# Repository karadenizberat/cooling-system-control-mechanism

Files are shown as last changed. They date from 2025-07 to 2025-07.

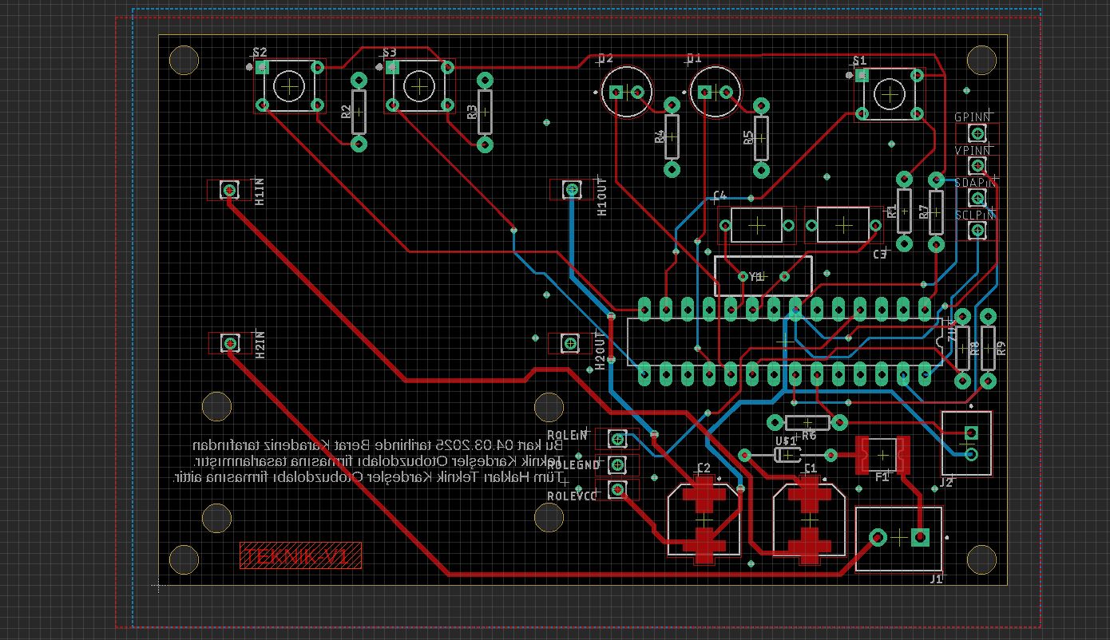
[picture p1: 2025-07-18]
img/coolingsystem-brd-img.JPG

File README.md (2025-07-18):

# 🚐 Vehicle Refrigerator Controller (ATmega-based)

This project is designed to control compact refrigerators used in
vehicles. It is based on an ATmega microcontroller and includes:

-   ❄️ Real-time temperature monitoring with an NTC sensor\
-   🔌 Relay control for compressor on/off\
-   📟 OLED display to show ambient and target temperatures\
-   💾 EEPROM storage for saving power state and target temperature\
-   🔘 Button interface to adjust temperature and toggle system on/off

The system continuously monitors ambient temperature and activates the
cooling system when needed. It is ideal for automotive refrigeration
applications requiring reliability and efficiency.

------------------------------------------------------------------------

## 🛠️ Hardware Components

-   ATmega microcontroller (e.g. ATmega328P)
-   NTC Thermistor
-   Relay module (12V/24V depending on compressor)
-   OLED Display (SSD1306 - 128x64)
-   EEPROM (onboard)
-   Push Buttons (Increase / Decrease / Power)
-   Green & Red LEDs for status indication

------------------------------------------------------------------------

## 📁 File Structure

Vehicle-Fridge-Controller/ │ ├── kod/ → Arduino source code (.ino file)
├── eagle/ → Circuit schematic (.sch) & PCB layout (.brd) ├── img/ →
Circuit photos, 3D renders, real setup images └── README.md → Project
description (this file)

------------------------------------------------------------------------

## 🔧 Setup Instructions

1.  Upload the `.ino` code to the ATmega chip using Arduino or ISP
    method.
2.  Wire the components as shown in the schematic (see `eagle/` and
    `img/` folders).
3.  Adjust the target temperature using the buttons.
4.  OLED will show real-time ambient temperature, target, and system
    state.
5.  System state and target temperature are stored in EEPROM, so they
    persist after power-off.

------------------------------------------------------------------------

## 🇹🇷 Proje Açıklaması (Türkçe)

Bu proje, araçlarda kullanılan küçük buzdolaplarını kontrol etmek
amacıyla geliştirilmiştir. ATmega mikrodenetleyici tabanlıdır ve:

-   🌡️ NTC sensörü ile sıcaklık ölçümü\
-   🔁 Röle modülü ile kompresör kontrolü\
-   🖥️ OLED ekran ile sıcaklık ve sistem durumu gösterimi\
-   💾 EEPROM ile sıcaklık ve sistem durumu kaydı\
-   🔘 Butonlarla sıcaklık ayarlama ve sistemi aç/kapatma

Sistem, belirlenen hedef sıcaklığa göre otomatik olarak kompresörü
devreye alır veya durdurur.

------------------------------------------------------------------------

## 📸 Görseller

Aşağıda sistemin gerçek devresi, Eagle şeması ve çalışma görüntüleri yer
alabilir. Bunları `img/` klasöründe saklayın.

------------------------------------------------------------------------

## 🧠 Lisans ve Katkı

Bu proje MIT lisansı altındadır. Dilerseniz fork edip geliştirmelere
katkı sağlayabilirsiniz.

------------------------------------------------------------------------

## 📬 İletişim / Communication

Geliştirici / Developer : \[Berat Karadeniz\]\
GitHub: \[https://github.com/karadenizberat\] LinkedIn:
\[https://www.linkedin.com/in/karadenizberat/\]

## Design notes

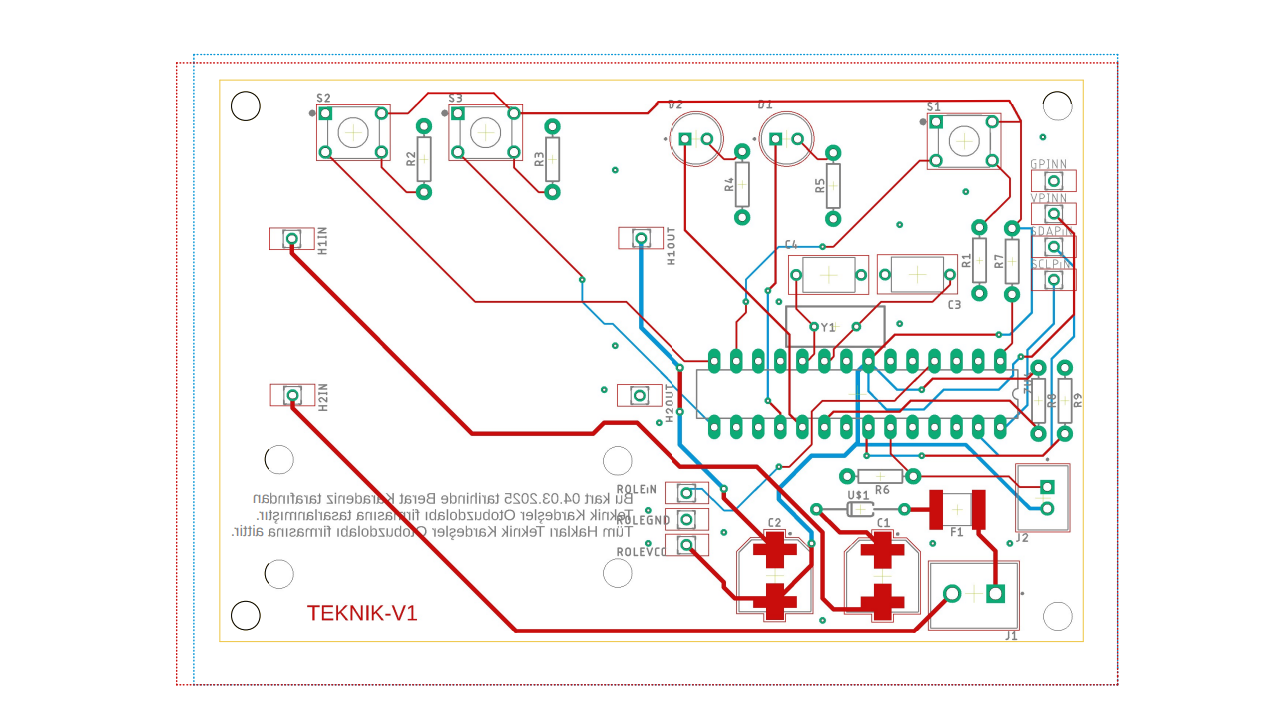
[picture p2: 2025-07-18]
img/cooling-system-img.png

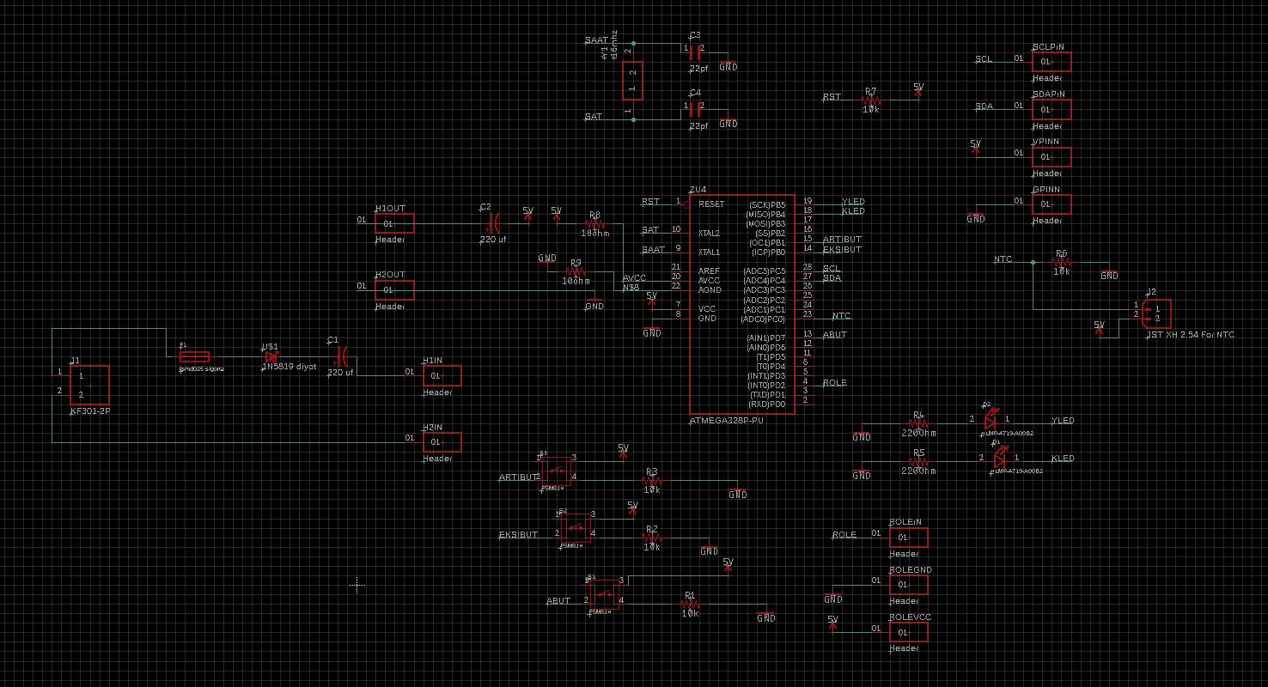
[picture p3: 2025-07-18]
img/coolingsystem-sch-img.JPG

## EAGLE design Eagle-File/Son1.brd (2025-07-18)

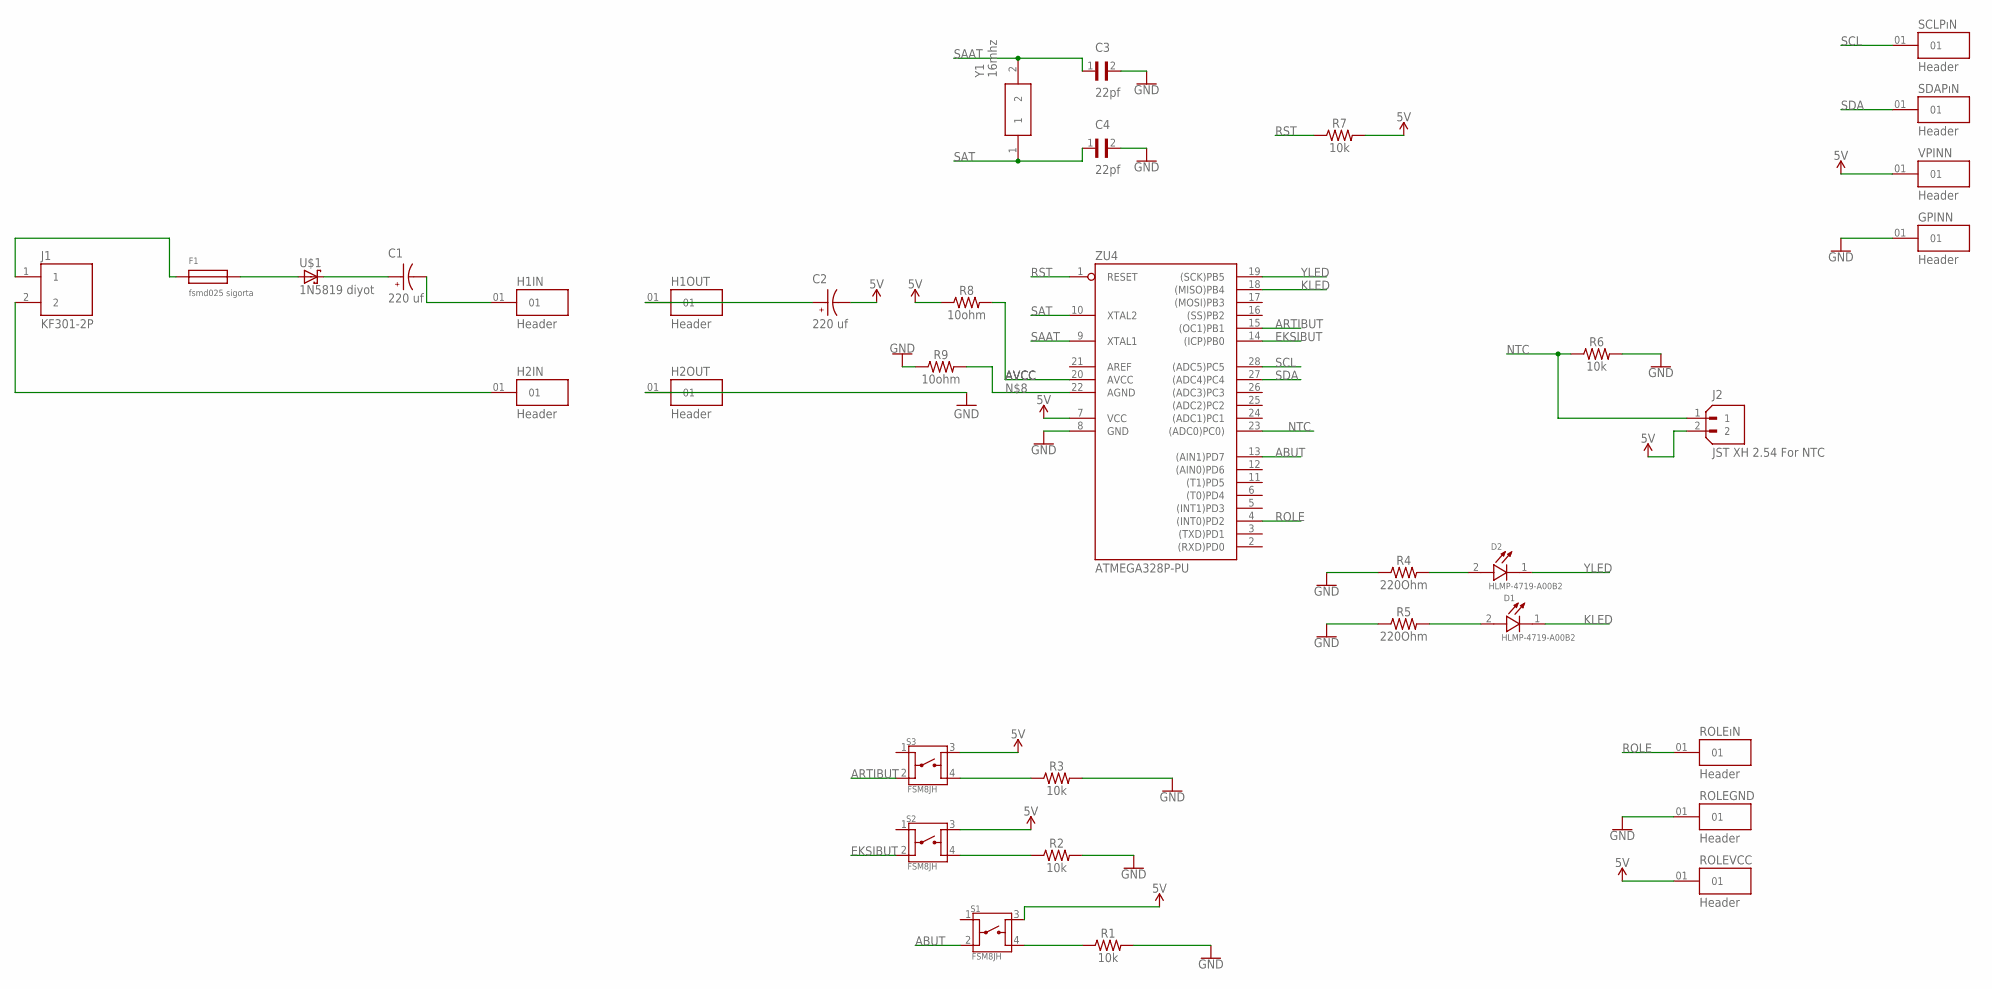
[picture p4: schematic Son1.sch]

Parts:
C1, C2: 220 uf; CAP_EEEFP1E101AV
C3, C4: 22pf; CAP_DE21XSA220KN3AX02F
D1, D2: HLMP-4719-A00B2; LEDRD254W47D584H1078
F1: fsmd025 sigorta; 0ZCN
GPINN: Header; SAMTEC_MTMM-101-X-X-S-X
H1IN, H1OUT, H2IN, H2OUT: Header; SAMTEC_MTMM-101-X-X-S-X
J1: KF301-2P; HANDSON_KF301-2P
J2: JST XH 2.54 For NTC; JST_B2B-XH-A(LF)(SN)
R1, R2, R3, R6, R7: 10k; AXIAL-0.3
R4, R5: 220Ohm; AXIAL-0.3
R8, R9: 10ohm; AXIAL-0.3
ROLEGND: Header; SAMTEC_MTMM-101-X-X-S-X
ROLEVCC: Header; SAMTEC_MTMM-101-X-X-S-X
ROLEıN: Header; SAMTEC_MTMM-101-X-X-S-X
S1, S2, S3: FSM8JH; SW_FSM8JH
SCLPıN: Header; SAMTEC_MTMM-101-X-X-S-X
SDAPıN: Header; SAMTEC_MTMM-101-X-X-S-X
U$1: 1N5819 diyot; SOD68
VPINN: Header; SAMTEC_MTMM-101-X-X-S-X
Y1: 16mhz; HC49SLF_1
ZU4: ATMEGA328P-PU; DIL28-3

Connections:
5V: C2.2, J2.2, R7.P$2 (2), R8.P$1 (1), ROLEVCC.01, S1.3, S2.3, S3.3, VPINN.01, ZU4.7 (VCC)
ABUT: S1.2, ZU4.13 ((AIN1)PD7)
ARTIBUT: S3.2, ZU4.15 ((OC1)PB1)
AVCC: R8.P$2 (2), ZU4.20 (AVCC)
EKSIBUT: S2.2, ZU4.14 ((ICP)PB0)
GND: C3.2, C4.2, GPINN.01, H2OUT.01, R1.P$2 (2), R2.P$2 (2), R3.P$2 (2), R4.P$1 (1), R5.P$1 (1), R6.P$2 (2), R9.P$1 (1), ROLEGND.01, ZU4.8 (GND)
KLED: D1.1 (C), ZU4.18 ((MISO)PB4)
unnamed: F1.P$2, U$1.A
unnamed: F1.P$1, J1.1
unnamed: C1.1, U$1.C (K)
unnamed: C1.2, H1IN.01
unnamed: H2IN.01, J1.2
unnamed: C2.1, H1OUT.01
unnamed: R1.P$1 (1), S1.4
unnamed: R9.P$2 (2), ZU4.22 (AGND)
unnamed: R2.P$1 (1), S2.4
unnamed: R3.P$1 (1), S3.4
unnamed: D1.2 (A), R5.P$2 (2)
unnamed: D2.2 (A), R4.P$2 (2)
NTC: J2.1, R6.P$1 (1), ZU4.23 ((ADC0)PC0))
ROLE: ROLEıN.01, ZU4.4 ((INT0)PD2)
RST: R7.P$1 (1), ZU4.1 (RESET)
SAAT: C3.1, Y1.2, ZU4.9 (XTAL1)
SAT: C4.1, Y1.1, ZU4.10 (XTAL2)
SCL: SCLPıN.01, ZU4.28 ((ADC5)PC5)
SDA: SDAPıN.01, ZU4.27 ((ADC4)PC4)
YLED: D2.1 (C), ZU4.19 ((SCK)PB5)

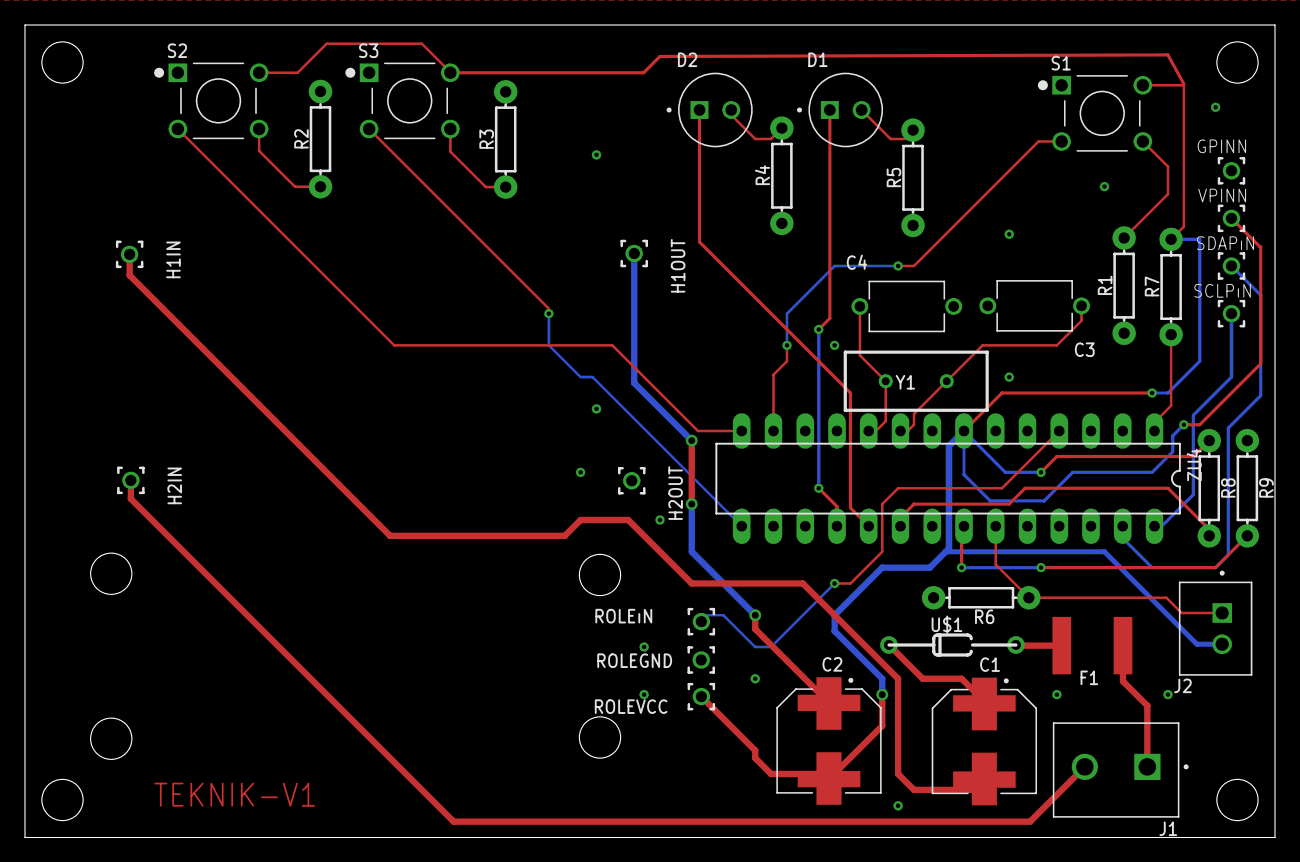
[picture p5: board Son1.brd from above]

Board: 2 copper layers, 100.0 x 65.0 mm, 35 parts (0 on the bottom side), 27 nets.

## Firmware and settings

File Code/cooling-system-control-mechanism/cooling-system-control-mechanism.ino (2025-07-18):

#include <Wire.h>                                                          //including necessary libraries
#include <EEPROM.h>                          
#include <Adafruit_GFX.h>
#include <Adafruit_SSD1306.h>

#define SCREEN_WIDTH 128                                                   //Adjusting OLED screen sizes                   
#define SCREEN_HEIGHT 64
Adafruit_SSD1306 display(SCREEN_WIDTH, SCREEN_HEIGHT, &Wire, -1);

// Pinler
const int ROLE_PIN = 2;                                                    //relay pin
const int YESIL_LED = 13;                                                  //Green-Led
const int KIRMIZI_LED = 12;                                                //Red-Led
const int artirButon = 8;                                                  //increase button
const int azaltButon = 9;                                                  //decrement button
const int sistemButon = 7;                                                 //Open-Close button

// NTC Sensör ayarları 
const int ntcPin = A0;                                                     //NTC sensor mathematical settings
const float beta = 3950.0; 
const float roomTempResistance = 100000.0;
const float nominalTemp = 25.0;
const float nominalResistance = 100000.0;

// Değişkenler                                                             //variables
int hedefSicaklik = 5;
int sistemDurumu = 0;
unsigned long sonGuncellemeZamani = 0;
const unsigned long ekranGuncellemeAraligi = 500;
bool artirildi = false;
bool azaltildi = false;
bool sistemButonaBasildi = false;

void setup() {
  pinMode(ROLE_PIN, OUTPUT);
  pinMode(YESIL_LED, OUTPUT);
  pinMode(KIRMIZI_LED, OUTPUT);
  pinMode(sistemButon, INPUT_PULLUP);
  pinMode(artirButon, INPUT_PULLUP);
  pinMode(azaltButon, INPUT_PULLUP);

  Serial.begin(9600);

  if (!display.begin(SSD1306_SWITCHCAPVCC, 0x3C)) {
    Serial.println(F("OLED baglanti hatasi!"));
    while (1);
  }

  display.clearDisplay();
  display.setTextSize(1);
  display.setTextColor(SSD1306_WHITE);
  display.setCursor(0, 0);
  display.println(F("Sistem baslatiliyor"));                             //Printing text on the OLED screen "system initializing"
  display.display();
  delay(200);

  hedefSicaklik = EEPROM.read(0);                                        //setting the temperature to the value entered by the user
  sistemDurumu = EEPROM.read(1);
  if (hedefSicaklik < -20 || hedefSicaklik > 10) hedefSicaklik = 5;
  if (sistemDurumu != 0 && sistemDurumu != 1) sistemDurumu = 0;
}

float readTemperature() {
  int adcValue = analogRead(ntcPin);
  if (adcValue == 0) adcValue = 1;

  float resistance = (1023.0 / (float)adcValue) - 1.0;
  resistance = roomTempResistance * resistance;

  float steinhart;
  steinhart = resistance / nominalResistance;
  steinhart = log(steinhart);
  steinhart /= beta;
  steinhart += 1.0 / (nominalTemp + 273.15);
  steinhart = 1.0 / steinhart;
  steinhart -= 273.15;

  return steinhart;
}

void loop() {
  unsigned long simdikiZaman = millis();

  // Sistem butonu (aç/kapa)                                               //system button open close
 if (digitalRead(sistemButon) == HIGH && !sistemButonaBasildi) {
  sistemDurumu = !sistemDurumu;
  EEPROM.write(1, sistemDurumu);
  sistemButonaBasildi = true;
 }

 if (digitalRead(sistemButon) == LOW) {
  sistemButonaBasildi = false;
 }

  // Sistem kapalıysa
  if (sistemDurumu == 0) {
    digitalWrite(ROLE_PIN, HIGH);
    digitalWrite(YESIL_LED, LOW);
    digitalWrite(KIRMIZI_LED, LOW);

    display.clearDisplay();
    display.setCursor(0, 0);
    display.println(F("Sistem Kapali"));
    display.display();
    return;
  }

  // Sıcaklık ölçümü                                                      //temperature measurement
  float sicaklik = readTemperature();

  // Röle ve LED kontrolü
  if (sicaklik >= hedefSicaklik + 3) {
    digitalWrite(ROLE_PIN, LOW);
    digitalWrite(YESIL_LED, HIGH);
    digitalWrite(KIRMIZI_LED, LOW);
  } else if (sicaklik <= hedefSicaklik) {
    digitalWrite(ROLE_PIN, HIGH);
    digitalWrite(YESIL_LED, LOW);
    digitalWrite(KIRMIZI_LED, HIGH);
  }

  // Artırma butonu (tek basışla artış)
  if (digitalRead(artirButon) == HIGH && !artirildi) {
    hedefSicaklik = min(hedefSicaklik + 1, 10);
    EEPROM.write(0, hedefSicaklik);
    sonGuncellemeZamani = 0;
    artirildi = true;
  }
  if (digitalRead(artirButon) == LOW) {
    artirildi = false;
  }

  // Azaltma butonu (tek basışla azalış)
  if (digitalRead(azaltButon) == HIGH && !azaltildi) {
    hedefSicaklik = max(hedefSicaklik - 1, -20);
    EEPROM.write(0, hedefSicaklik);
    sonGuncellemeZamani = 0;
    azaltildi = true;
  }
  if (digitalRead(azaltButon) == LOW) {
    azaltildi = false;
  }

  // Ekran güncelleme
  if (simdikiZaman - sonGuncellemeZamani >= ekranGuncellemeAraligi) {
    sonGuncellemeZamani = simdikiZaman;

    display.clearDisplay();
    display.setTextSize(1);
    display.setCursor(0, 0);
    display.print(F("Teknik Kardesler"));                               //Printing text on the OLED screen"Company name"
    
    display.setCursor(0, 15);
    display.print(F("Ortam: "));
    display.print(sicaklik, 1);
    display.print(F(" C"));

    display.setCursor(0, 30);
    display.print(F("Hedef: "));
    display.print(hedefSicaklik);
    display.print(F(" C"));

    display.setCursor(0, 45);
    display.print(F("Durum: "));
    display.print(digitalRead(ROLE_PIN) ? F("KAPALI") : F("ACIK"));

    display.display();
  }
}

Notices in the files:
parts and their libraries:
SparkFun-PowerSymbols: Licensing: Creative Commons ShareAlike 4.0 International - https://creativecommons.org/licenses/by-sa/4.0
